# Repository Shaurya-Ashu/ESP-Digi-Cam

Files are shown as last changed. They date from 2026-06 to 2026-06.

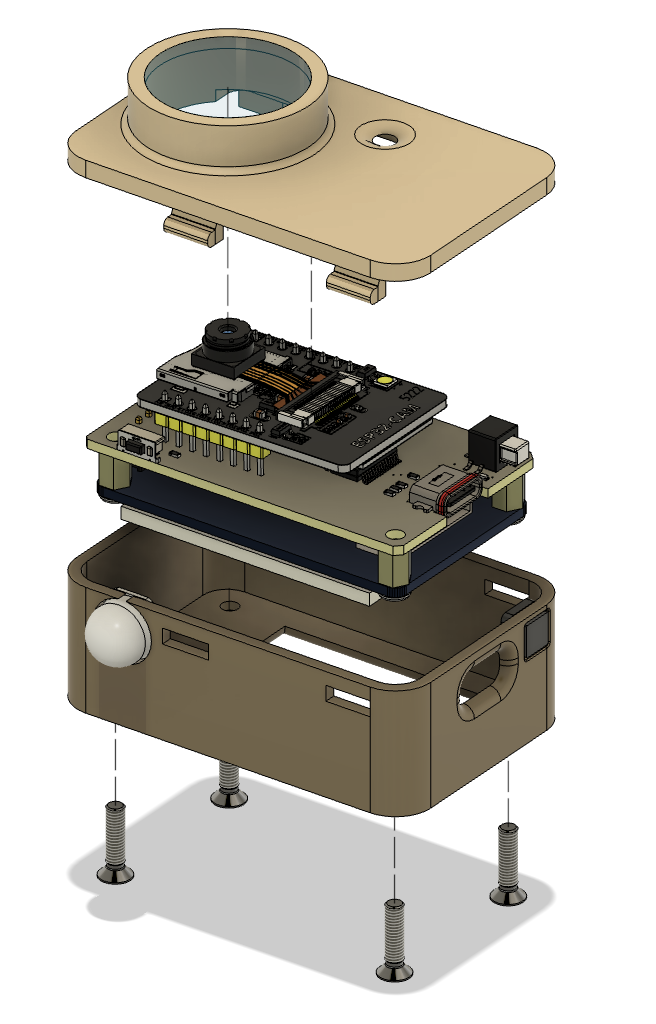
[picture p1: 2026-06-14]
Assembly/Screenshot 2026-06-14 at 9.49.44 PM.png

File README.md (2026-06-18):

# ESP-Digi-Cam
 It's a mini digicam powered by ESP32 cam module with
 an integrated TFT display of 1.8 inch and USB‑C powered / programming enclosed inside a 3D Printed custom case.
 with wifi sharing of img's.
# Zine
Frame 3-2

# Why not to build this 

 * If you already have one
 * If you are building one
 * If you don't like camera
 * IDK , i am runing out of reasons not to build it

# Schematics



Brains/Camera:
 ESP32 CAM best and simplest for this project 

USB-C:
 an external type - c port for programing and power

UART-USB Converter:
 I have used FT232RL to convert UART to USB so that we can program the ESP32 CAM

Display:
 A 1.8 inch tft display 128 x 160 pix connected with spi interface to ESP32 CAM

Battery:
 I have added a charging module so if you want to iuntigrate a battery in it you can .

# PCB 
it is a very simple 2 layered PCB designed in EasyEDA connecting all the parts together.

Top Layer

 Screenshot 2026-06-14 at 3 21 17 PM

Bottom Layer

Screenshot 2026-06-14 at 3 21 30 PM

# CAD

so I've designed a 3D printed case for this digicam in Fusion 360.
it is simple 2 part case with different parts for switches.

Untitled_2026-Jun-14_05-26-15PM-000_CustomizedView51561765880_png_alpha
Untitled_2026-Jun-14_06-01-42PM-000_CustomizedView3772994715_png_alpha



# Assembly

The top part is screwed in the PCB & And the bottom part is just plug in.
Before packing the PCB we need to put on the button caps in their place.

SCREW M2
Screenshot 2026-06-14 at 9 49 44 PM

If you want to add battery, you can include it between the display and the PCB

# Firmware 

It will show you the live footage and if you click the picture, it will be shown on your phone on the web portal
As I missed a very important part in developing this project that the in-built SD card reader in the ESP32 cam model is connected with the same pins as the SPI connection of TFT display.

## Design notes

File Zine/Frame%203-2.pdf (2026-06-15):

# lESlP JDngnCaum

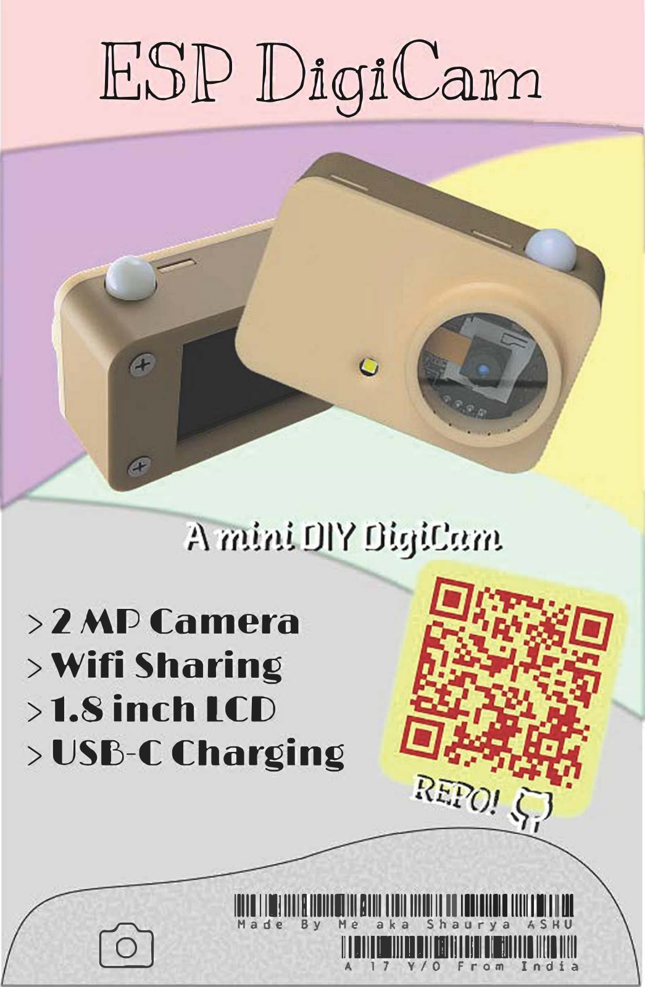
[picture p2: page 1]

> l M() Camera
> Wifi Sharin
> 1.S inch LCI)
> USl:>-C Charin

111111 11111111111111111111111 11111 11111 11 ll llllllllll lllll I II I II I

@] | Hade | Sy | He aka Shaurya ASHU
II IIIIIIIIIIIII Ill llll 11111111111111111
A | 17 | Y/0 | From | India

•

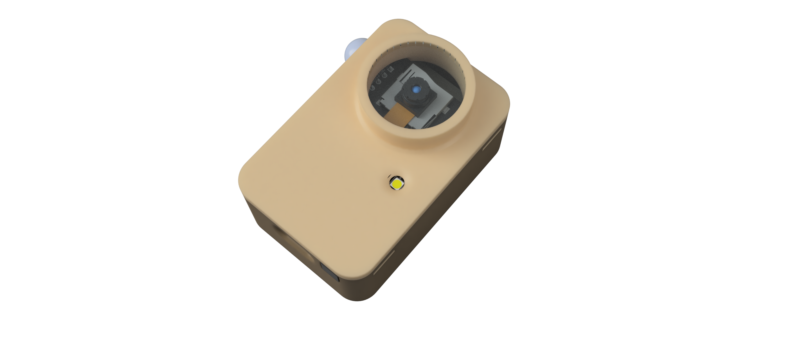
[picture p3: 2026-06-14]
CAD/Untitled_2026-Jun-14_05-26-15PM-000_CustomizedView51561765880_png_alpha.png

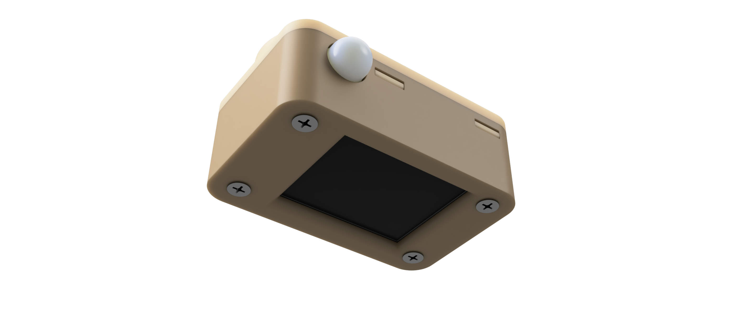
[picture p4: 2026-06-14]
CAD/Untitled_2026-Jun-14_06-01-42PM-000_CustomizedView3772994715_png_alpha.png

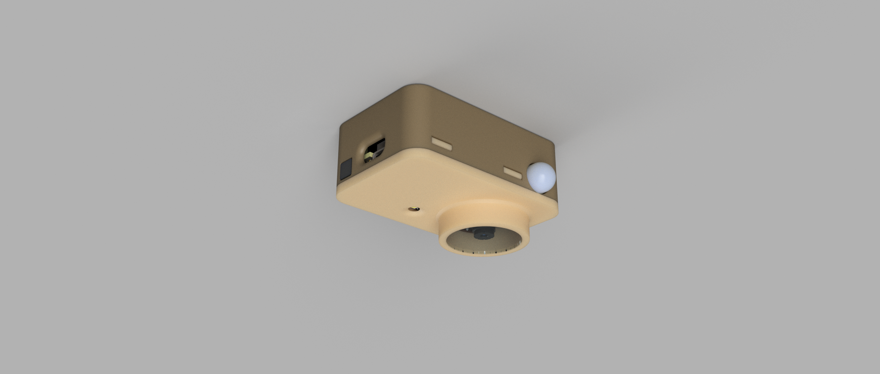
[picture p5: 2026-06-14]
CAD/Untitled v4.png

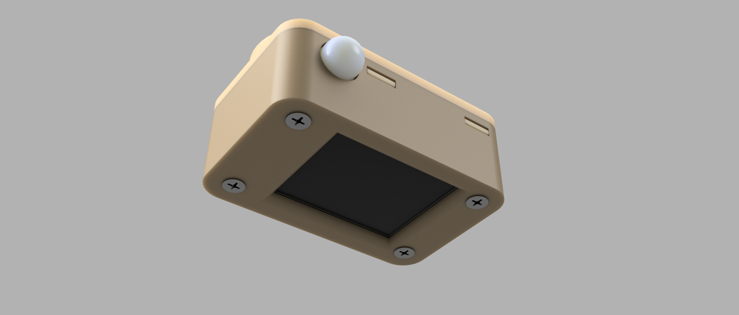
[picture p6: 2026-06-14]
CAD/Untitled v5.png

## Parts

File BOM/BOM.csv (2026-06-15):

Item No. | Item | Description | Quantity | Price per unit ($) | Total price ($) | Link
1 | 100nF | C0603 | 4 | 2.5730 | 10.2920 | https://www.lcsc.com/product-detail/C14663.html
2 | 10uF | C0603 | 1 | 2.5730 | 2.5730 | https://www.lcsc.com/product-detail/C19702.html
3 | 22uf | C0603 | 2 | 2.5730 | 5.1460 | https://www.lcsc.com/product-detail/C109448.html
4 | 1uH | IND-SMD_L4.2-W4.2_MCW-0420 | 1 | 0.0550 | 0.0550 | https://www.lcsc.com/search?q=C609522
5 | 1.8inch LCD Module | LCD-TH_L56.5-W34.0_1-8INCH-LCD-MODULE | 1 | 1.0063 | 1.0063 | https://www.lcsc.com/search?q=C359940
6 | 4K7 | R0603 | 1 | 2.5730 | 2.5730 | https://www.lcsc.com/product-detail/C2889370.html
7 | 10K | R0603 | 4 | 2.5730 | 10.2920 | https://www.lcsc.com/product-detail/chip-resistor-surface-mount_tyohm-rmc-0603-10k-j-n_C5362358.html
8 | 270 | R0603 | 3 | 2.5730 | 7.7190 | https://www.lcsc.com/product-detail/C351661.html
9 | 5K | R0603 | 2 | 2.5730 | 5.1460 | https://www.lcsc.com/product-detail/C2889373.html
10 | 732K | R0603 | 1 | 2.5730 | 2.5730 | https://www.lcsc.com/product-detail/C861325.html
11 | 100K | R0603 | 1 | 2.5730 | 2.5730 | https://www.lcsc.com/product-detail/C2889376.html
12 | 2k | R0603 | 1 | 2.5730 | 2.5730 | https://www.lcsc.com/product-detail/C269690.html
13 | YLED0603B | LED0603-FD | 2 | 0.0010 | 0.0020 | https://www.lcsc.com/search?q=C19171394
14 | POWER | SW-SMD_XKB5858-W-F-75 | 1 | 0.0452 | 0.0452 | https://www.lcsc.com/search?q=C780037
15 | 1TS002G-1400-3500-CT | KEY-SMD_1TS002G | 1 | 0.0072 | 0.0072 | https://www.lcsc.com/search?q=C319373
16 | YLED0603R | LED0603-FD | 1 | 0.0010 | 0.0010 | https://www.lcsc.com/search?q=C19171390
17 | ESP32-CAM | COMM-TH_16P-L40.0-W27.0-P2.54_ESP32-CAM | 1 | 1.1280 | 1.1280 | https://www.lcsc.com/search?q=C277946
18 | FT232RL | SSOP-28_L10.2-W5.3-P0.65-LS7.8-BL | 1 | 1.1708 | 1.1708 | https://www.lcsc.com/search?q=C490691
19 | TPS61023DRLR | SOT-563_L1.6-W1.2-P0.50-LS1.6-BR | 1 | 0.0397 | 0.0397 | https://www.lcsc.com/search?q=C919459
20 | JST Right-Angle Connector - SMD 2-Pin (Black) | CONN-SMD_JST-PH-2-SMT-RA | 1 | 0.0059 | 0.0059 | https://www.lcsc.com/search?q=C9900141337
21 | MCP73831T-2ACI/OT-HXY | SOT-23-5_L2.9-W1.6-P0.95-LS2.8-TL | 1 | 0.1005 | 0.1005 | https://www.lcsc.com/search?q=C42432883
22 | GT-USB-7100A | USB-C-SMD_GT-USB-7100A | 1 | 0.0728 | 0.0728 | https://www.lcsc.com/search?q=C7469646
23 | PCB Fabrication | PCB (2-layer), 5pcs | 5 | 2.0000 | 10.0000
24 | Enclosure/Case | Custom case for board | 1 | 5.0000 | 5.0000
25 | Battery | 1S 3.7V 500mAh LiPo battery | 1 | 2.0000 | 2.0000 | https://loftyagrotech.com/wly502025-3-7v-200mah-1s-lipo-battery-ndbc/
 |  |  |  |  | GRAND TOTAL ($) | 72.0944

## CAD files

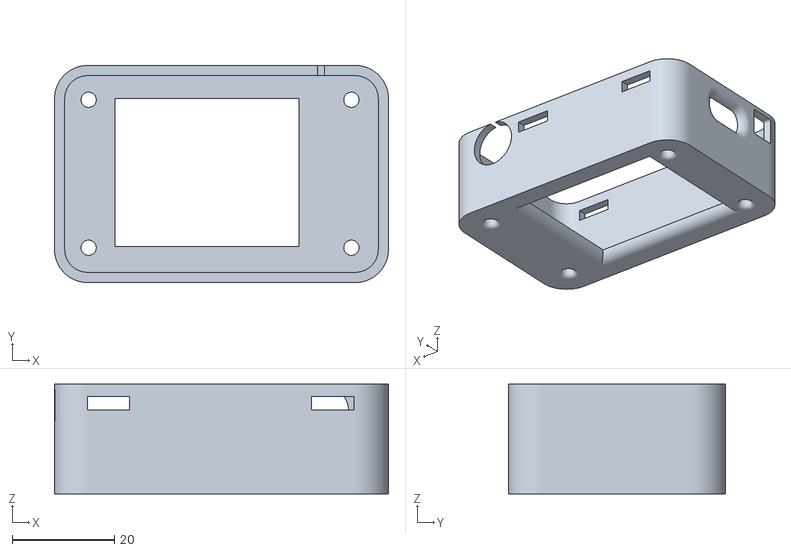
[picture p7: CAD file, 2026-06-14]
CAD/Lower_case.stl
65.5 x 42.6 x 21.5

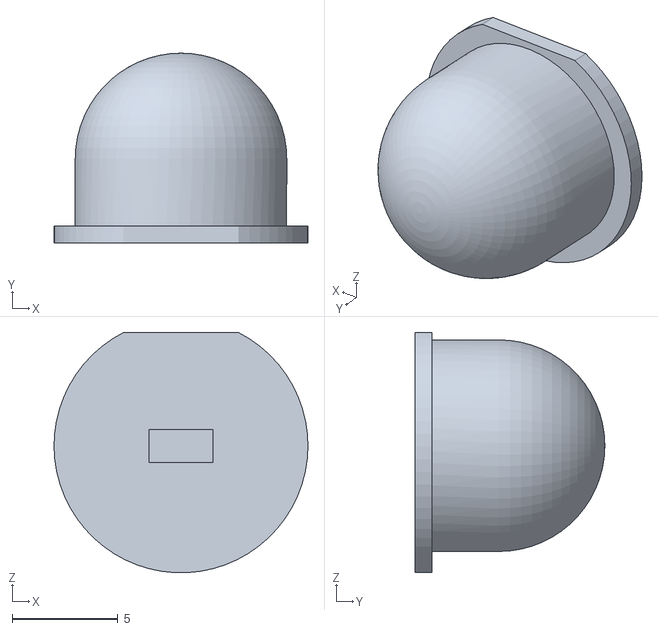
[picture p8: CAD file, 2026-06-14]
CAD/click.stl
12.0 x 8.97 x 11.3

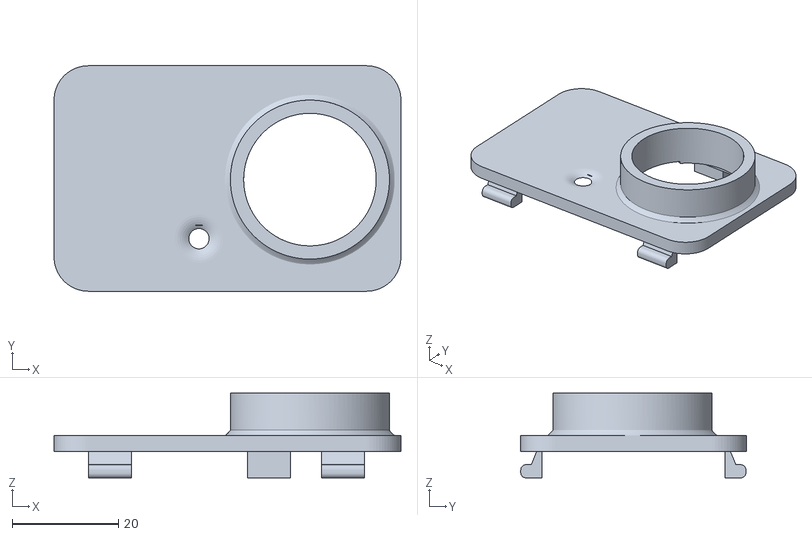
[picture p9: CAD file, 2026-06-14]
CAD/Top_case.stl
65.5 x 42.6 x 16.0

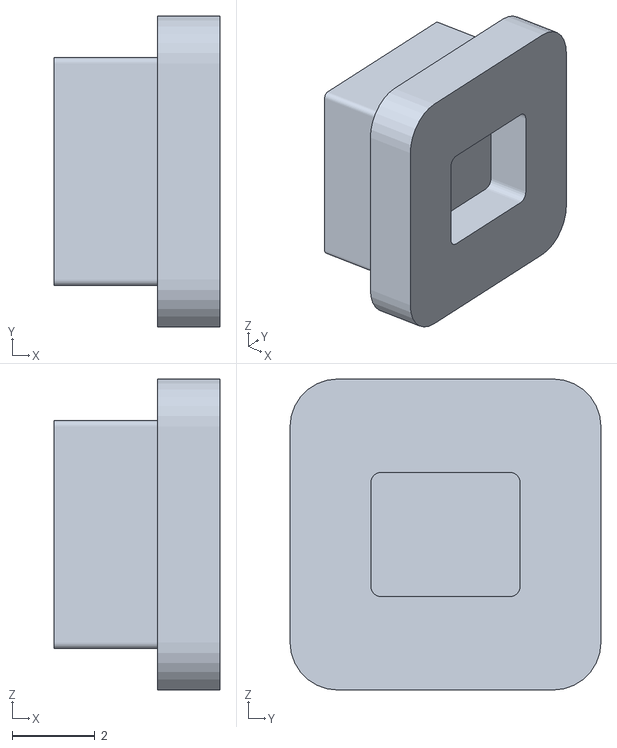
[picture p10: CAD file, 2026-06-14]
CAD/Power_button.stl
4.00 x 7.50 x 7.50

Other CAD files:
CAD/full file.f3z

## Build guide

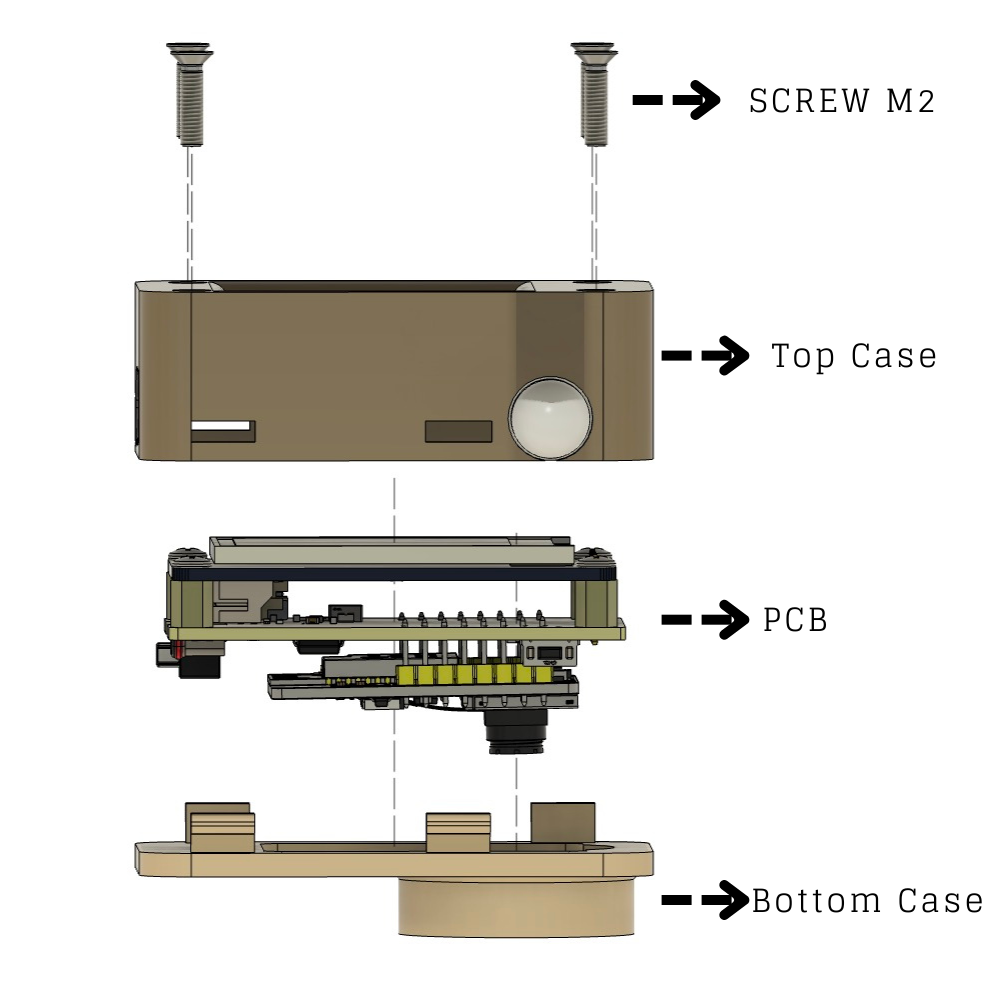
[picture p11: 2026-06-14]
Assembly/SCREW M2.png

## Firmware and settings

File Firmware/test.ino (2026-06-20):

#include "esp_camera.h"
#include <SPI.h>
#include <Adafruit_GFX.h>
#include <Adafruit_ST7735.h>
#define TFT_SCK    14   
#define TFT_MOSI   13   
#define TFT_CS     15  
#define TFT_DC      2   
#define TFT_RST    12   
#define TFT_BL      4   

#define BUTTON_PIN 16   


#define TFT_INIT_TAB INITR_BLACKTAB



#define PWDN_GPIO_NUM     32
#define RESET_GPIO_NUM    -1
#define XCLK_GPIO_NUM      0
#define SIOD_GPIO_NUM     26
#define SIOC_GPIO_NUM     27
#define Y9_GPIO_NUM       35
#define Y8_GPIO_NUM       34
#define Y7_GPIO_NUM       39
#define Y6_GPIO_NUM       36
#define Y5_GPIO_NUM       21
#define Y4_GPIO_NUM       19
#define Y3_GPIO_NUM       18
#define Y2_GPIO_NUM        5
#define VSYNC_GPIO_NUM    25
#define HREF_GPIO_NUM     23
#define PCLK_GPIO_NUM     22

Adafruit_ST7735 tft = Adafruit_ST7735(TFT_CS, TFT_DC, TFT_MOSI, TFT_SCK, TFT_RST);

bool frozen = false;
bool lastButtonState = HIGH;
unsigned long lastDebounceTime = 0;
const unsigned long debounceDelay = 40;

void initCamera() {
  camera_config_t config;
  config.ledc_channel = LEDC_CHANNEL_0;
  config.ledc_timer   = LEDC_TIMER_0;
  config.pin_d0 = Y2_GPIO_NUM;
  config.pin_d1 = Y3_GPIO_NUM;
  config.pin_d2 = Y4_GPIO_NUM;
  config.pin_d3 = Y5_GPIO_NUM;
  config.pin_d4 = Y6_GPIO_NUM;
  config.pin_d5 = Y7_GPIO_NUM;
  config.pin_d6 = Y8_GPIO_NUM;
  config.pin_d7 = Y9_GPIO_NUM;
  config.pin_xclk  = XCLK_GPIO_NUM;
  config.pin_pclk  = PCLK_GPIO_NUM;
  config.pin_vsync = VSYNC_GPIO_NUM;
  config.pin_href  = HREF_GPIO_NUM;
  config.pin_sscb_sda = SIOD_GPIO_NUM;
  config.pin_sscb_scl = SIOC_GPIO_NUM;
  config.pin_pwdn  = PWDN_GPIO_NUM;
  config.pin_reset = RESET_GPIO_NUM;
  config.xclk_freq_hz = 20000000;
  config.pixel_format = PIXFORMAT_RGB565;
  config.frame_size   = FRAMESIZE_QQVGA;   
  config.fb_count     = 2;
  config.fb_location  = CAMERA_FB_IN_PSRAM;
  config.grab_mode    = CAMERA_GRAB_LATEST;

  esp_err_t err = esp_camera_init(&config);
  if (err != ESP_OK) {
    Serial.printf("Camera init failed: 0x%x\n", err);
    tft.fillScreen(ST77XX_BLACK);
    tft.setTextColor(ST77XX_RED);
    tft.setCursor(5, 60);
    tft.print("Camera init failed");
    while (true) delay(1000);
  }

  
  sensor_t *s = esp_camera_sensor_get();
  s->set_vflip(s, 1);
  s->set_hmirror(s, 1);
}


void drawFrame(camera_fb_t *fb) {
  int srcW = fb->width;
  int srcH = fb->height;
  int xOffset = (srcW - tft.width()) / 2;
  if (xOffset < 0) xOffset = 0;

  uint16_t *pixels = (uint16_t *)fb->buf;
  int drawW = min((int)tft.width(), srcW);
  int drawH = min((int)tft.height(), srcH);

  tft.startWrite();
  tft.setAddrWindow(0, 0, drawW, drawH);
  for (int y = 0; y < drawH; y++) {
    for (int x = 0; x < drawW; x++) {
      uint16_t px = pixels[y * srcW + (x + xOffset)];
      px = (px >> 8) | (px << 8); 
      tft.SPI_WRITE16(px);
    }
  }
  tft.endWrite();
}

void setup() {
  Serial.begin(115200);

  pinMode(BUTTON_PIN, INPUT_PULLUP);

  pinMode(TFT_BL, OUTPUT);
  digitalWrite(TFT_BL, HIGH); 

  tft.initR(TFT_INIT_TAB);
  tft.setRotation(0);
  tft.fillScreen(ST77XX_BLACK);
  tft.setTextColor(ST77XX_WHITE);
  tft.setTextSize(1);
  tft.setCursor(5, 5);
  tft.print("ESP DigiCam");
  delay(400);

  initCamera();
}

void loop() {
  bool reading = digitalRead(BUTTON_PIN);
  if (reading != lastButtonState) {
    lastDebounceTime = millis();
  }
  if ((millis() - lastDebounceTime) > debounceDelay) {
    if (reading == LOW && lastButtonState == HIGH) {
      frozen = !frozen;
    }
  }
  lastButtonState = reading;

  if (frozen) {
    delay(20);
    return; 
  }

  camera_fb_t *fb = esp_camera_fb_get();
  if (!fb) {
    Serial.println("Camera capture failed");
    delay(50);
    return;
  }

  drawFrame(fb);
  esp_camera_fb_return(fb);
}
